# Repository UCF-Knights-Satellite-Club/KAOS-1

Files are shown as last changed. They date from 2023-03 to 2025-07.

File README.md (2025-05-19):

# KAOS-1 Project
KAOS (Knight Air Observer Satellite)-1 is a 4U CubeSat that will be launched on a weather balloon to study atmospheric chemistry.

## Hardware
TODO: add hardware description

## Software
This project utilizes the Arduino ecosystem on a **DOIT ESP32 DEVKIT V1**. Unless stated otherwise, all libraries can be found in the Arduino IDE Library Manager.

### Prerequisites
- **Arduino ESP32 Core** ([installation instructions](https://docs.espressif.com/projects/arduino-esp32/en/latest/installing.html))
- **Adafruit BMP3XX Library** by Adafruit
- **Adafruit SCD30** by Adafruit
- **RTClib** by Adafruit
- **Adafruit MMA8451 Library** by Adafruit
- **Arducam_Mega** by Arducam

### Explanation
The flight software has five states. The first state is `CALIBRATION` which averages several altitude readings to determine a launch altitude. Next is `PREFLIGHT` which runs when KAOS-1 is on the ground and waiting to be released on the balloon. High acceleration or breaking an altitude threshold will move to the `ASCENT` state. In this state, KAOS-1 monitors acceleration to determine when it is in free fall. In free fall, the accelerometer will read close to zero. Once this condition is met, the state moves to `FREEFALL` where altitude is compared to the deployment altitude. Once deployment altitude is reached, the a buzzer is enabled and the state switches to `LANDING`.

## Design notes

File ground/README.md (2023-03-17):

# Ground Software
This is all software that will not be put onto the flight board.

# Examples
Hardware test programs, misc. test programs, mech cad files

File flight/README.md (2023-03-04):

# Flight Software
This folder is for storing flight software (the programs that our flight board will run for all necessary functions)

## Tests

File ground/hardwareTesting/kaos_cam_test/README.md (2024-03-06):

# KAOS Cam Test
Takes images using an ArduCam Mega SPI camera and writes them to an SD card.

## Required Libraries
- **ESP-32** by Espressif ([Install Instructions](https://docs.espressif.com/projects/arduino-esp32/en/latest/installing.html))
- **Arducam_Mega** by Arducam

## Wiring
|Chip |ESP32 |
|---|---|
|ArduCam SCK (White) | 18 (D18) |
|ArduCam MISO (Brown)  | 19 (D18) |
|ArduCam MOSI (Yellow) | 23 (D23) |
|ArduCam CS (Orange) | 17 (TX2) |
|SD CLK | 18 (D18) |
|SD DI | 23 (D23) |
|SD DO | 19 (D18) |
|SD CS | 15 (D15) |

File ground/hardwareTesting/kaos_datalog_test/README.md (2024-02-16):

# KAOS Datalog Test
Gathers data from the sensors and logs them to the SD card in CSV format. Also outputs data over the serial connection which can be viewed with the Arduino IDE Serial Plotter Tool.

## Required Libraries
- **ESP-32** by Espressif ([Install Instructions](https://docs.espressif.com/projects/arduino-esp32/en/latest/installing.html))
- **Adafruit SCD-30** by Adafruit
- **RTClib** by Adafruit
- **Adafruit BMP3XX Library** by Adafruit

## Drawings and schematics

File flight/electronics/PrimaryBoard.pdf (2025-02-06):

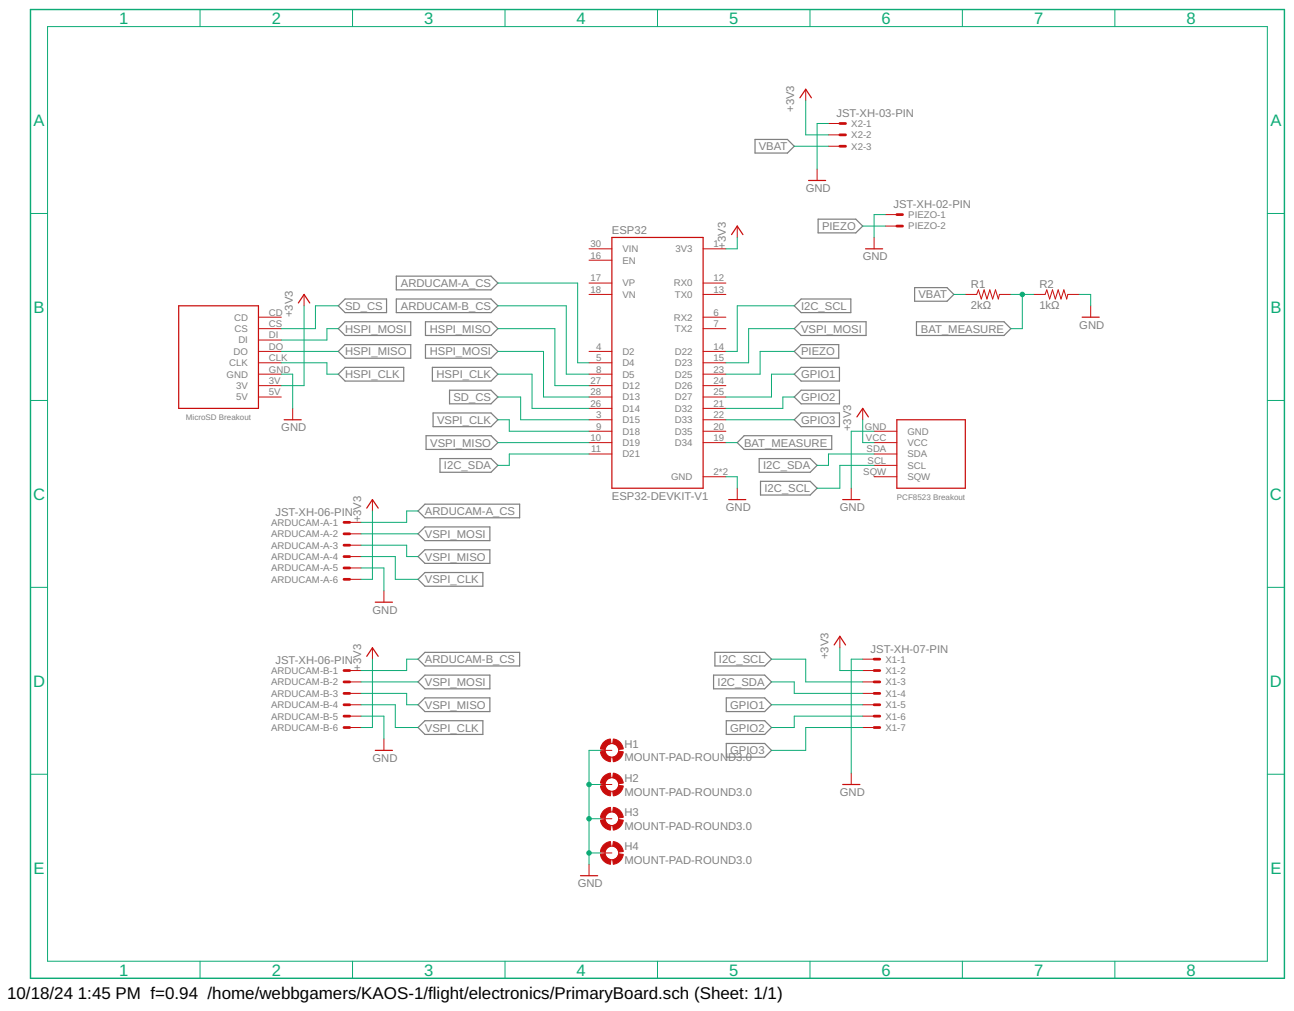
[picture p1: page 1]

GND JST-XH-06-PIN
ARDUCAM-A-1 ARDUCAM-A-2 ARDUCAM-A-3 ARDUCAM-A-4 ARDUCAM-A-5 ARDUCAM-A-6

JST-XH-06-PIN
ARDUCAM-B-1 ARDUCAM-B-2 ARDUCAM-B-3 ARDUCAM-B-4 ARDUCAM-B-5 ARDUCAM-B-6

10/18/24 1:45 PM f=0.94 /home/webbgamers/KAOS-1/flight/electronics/PrimaryBoard.sch (Sheet: 1/1)

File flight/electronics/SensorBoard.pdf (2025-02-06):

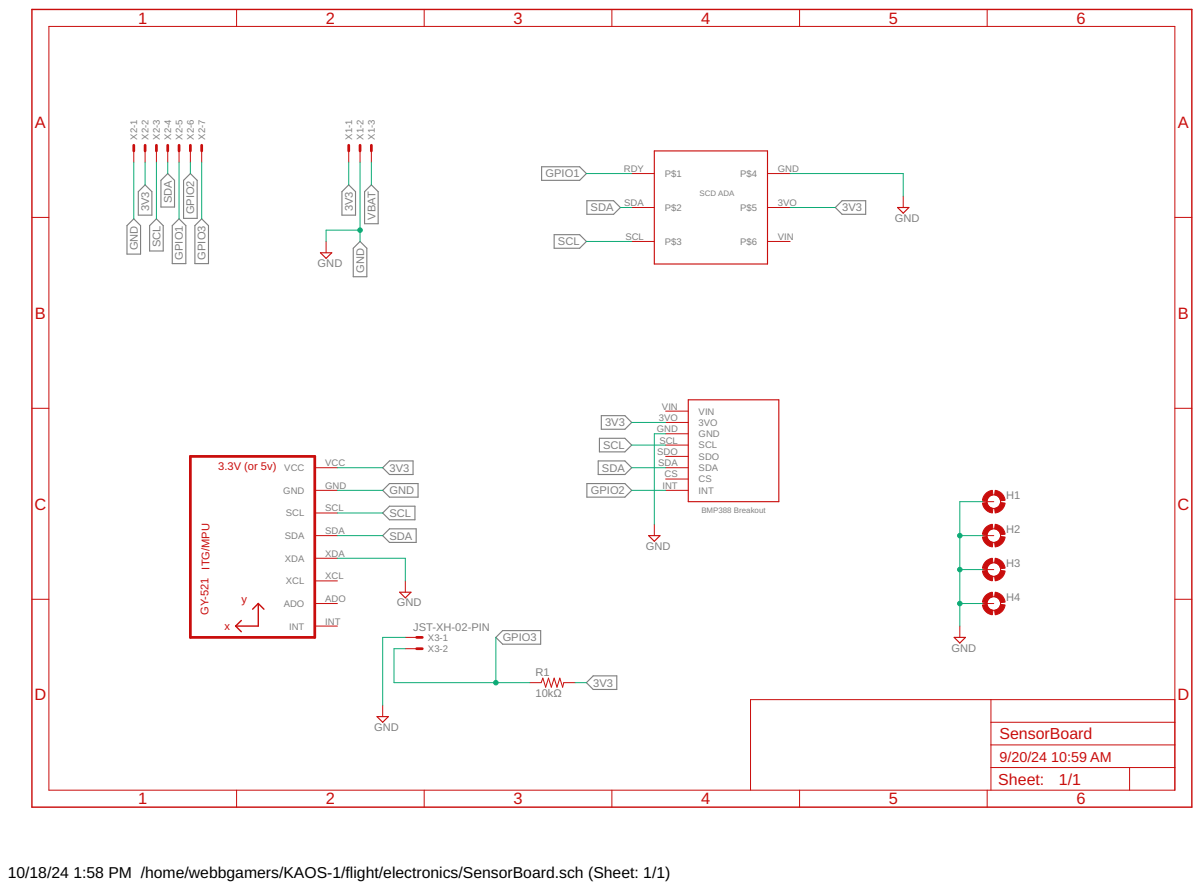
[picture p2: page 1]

10/18/24 1:58 PM /home/webbgamers/KAOS-1/flight/electronics/SensorBoard.sch (Sheet: 1/1)

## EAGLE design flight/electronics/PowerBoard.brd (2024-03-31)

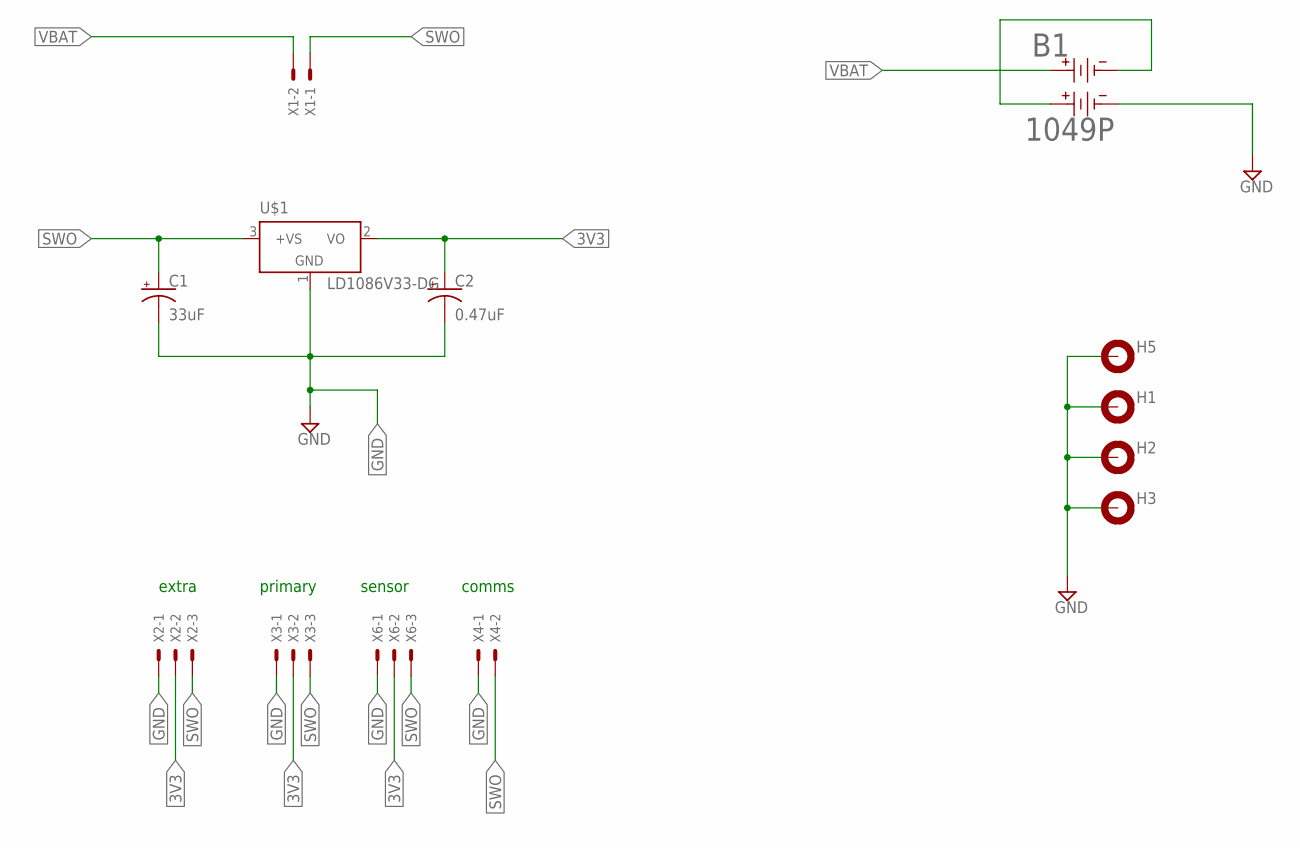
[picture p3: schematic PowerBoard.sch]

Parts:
B1: 1049P; 1049P_KEY
C1: 33uF; E2,5-5
C2: 0.47uF; E2,5-5
H1, H2, H3, H5: MOUNT-PAD-ROUND3.0; 3,0-PAD
U$1: LD1086V33-DG; TO220H
X1, X4: JST-XH-02-PIN; JST-XH_S2B
X2, X3, X6: JST-XH-03-PIN; JST-XH_S3B

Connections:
3V3: C2.+, U$1.2 (VO), X2.PIN2, X3.PIN2, X6.PIN2
GND: B1.3, C1.-, C2.-, H1.B3,0, H2.B3,0, H3.B3,0, H5.B3,0, U$1.1 (GND), X2.PIN1, X3.PIN1, X4.PIN1, X6.PIN1
unnamed: B1.2, B1.4
SWO: C1.+, U$1.3 (+VS), X1.PIN1, X2.PIN3, X3.PIN3, X4.PIN2, X6.PIN3
VBAT: B1.1, X1.PIN2

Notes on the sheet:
extra
primary
sensor
comms

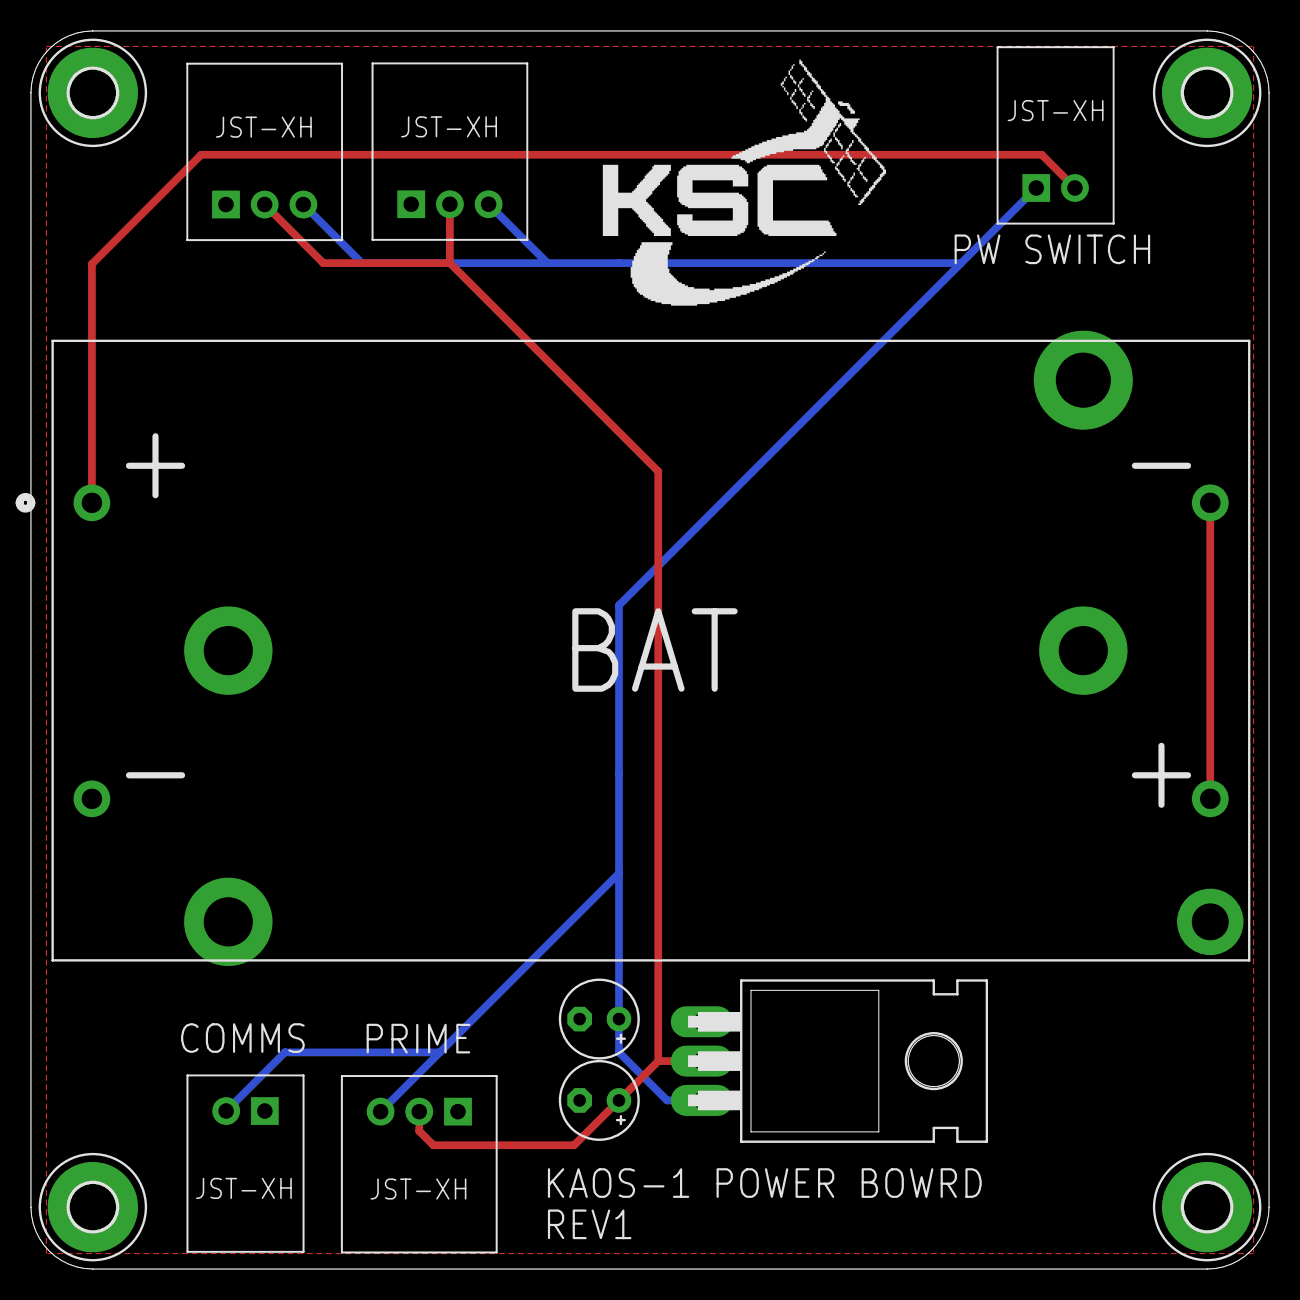
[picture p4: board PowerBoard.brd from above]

Board: 2 copper layers, 80.0 x 80.0 mm, 13 parts (0 on the bottom side), 5 nets.

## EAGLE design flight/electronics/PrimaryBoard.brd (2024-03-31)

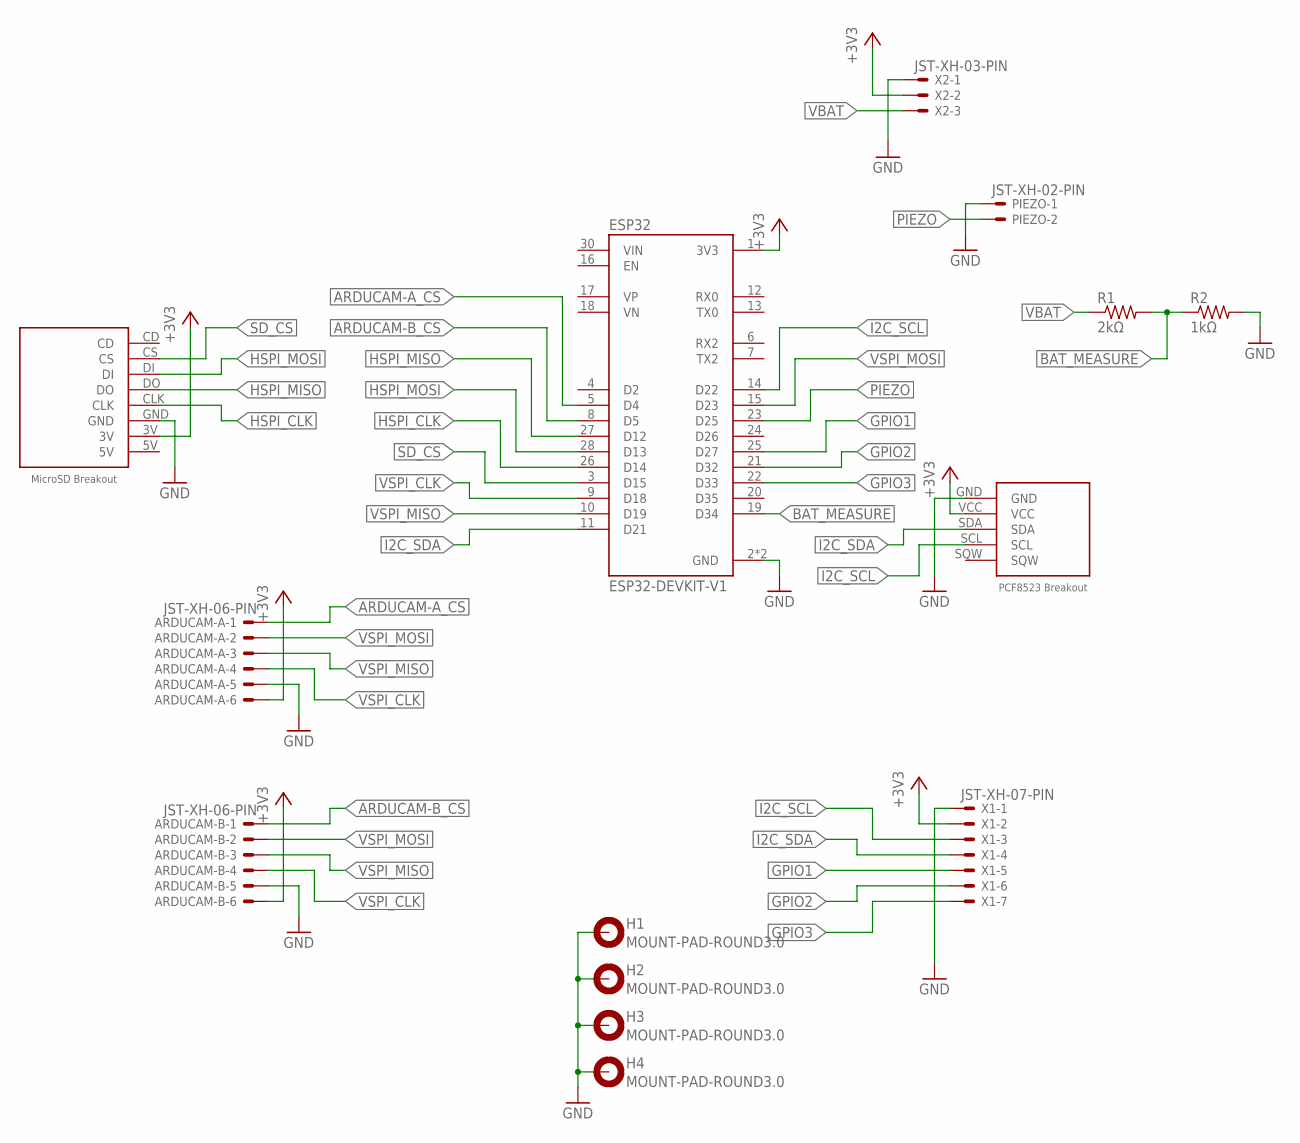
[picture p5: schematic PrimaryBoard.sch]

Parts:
ARDUCAM-A: JST-XH-06-PIN; JST-XH_S6B
ARDUCAM-B: JST-XH-06-PIN; JST-XH_S6B
ESP32: ESP32-DEVKIT-V1; MODULE_ESP32_DEVKIT_V1
H1, H2, H3, H4: MOUNT-PAD-ROUND3.0; 3,0-PAD
PIEZO: JST-XH-02-PIN; JST-XH_S2B
R1: 2kΩ; 0207/10
R2: 1kΩ; 0207/10
U$1: MICROSDBREAKOUT5V
U$2: PCF8523BREAKOUT
X1: JST-XH-07-PIN; JST-XH_S7B
X2: JST-XH-03-PIN; JST-XH_S3B

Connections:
+3V3: ARDUCAM-A.PIN6, ARDUCAM-B.PIN6, ESP32.1 (3V3), U$1.3V, U$2.VCC, X1.PIN2, X2.PIN2
ARDUCAM-A_CS: ARDUCAM-A.PIN1, ESP32.5 (D4)
ARDUCAM-B_CS: ARDUCAM-B.PIN1, ESP32.8 (D5)
BAT_MEASURE: ESP32.19 (D34), R1.2, R2.1
GND: ARDUCAM-A.PIN5, ARDUCAM-B.PIN5, ESP32.2 (GND), ESP32.29 (GND), H1.B3,0, H2.B3,0, H3.B3,0, H4.B3,0, PIEZO.PIN1, R2.2, U$1.GND, U$2.GND, X1.PIN1, X2.PIN1
GPIO1: ESP32.25 (D27), X1.PIN5
GPIO2: ESP32.21 (D32), X1.PIN6
GPIO3: ESP32.22 (D33), X1.PIN7
HSPI_CLK: ESP32.26 (D14), U$1.CLK
HSPI_MISO: ESP32.27 (D12), U$1.DO
HSPI_MOSI: ESP32.28 (D13), U$1.DI
I2C_SCL: ESP32.14 (D22), U$2.SCL, X1.PIN3
I2C_SDA: ESP32.11 (D21), U$2.SDA, X1.PIN4
PIEZO: ESP32.23 (D25), PIEZO.PIN2
SD_CS: ESP32.3 (D15), U$1.CS
VBAT: R1.1, X2.PIN3
VSPI_CLK: ARDUCAM-A.PIN4, ARDUCAM-B.PIN4, ESP32.9 (D18)
VSPI_MISO: ARDUCAM-A.PIN3, ARDUCAM-B.PIN3, ESP32.10 (D19)
VSPI_MOSI: ARDUCAM-A.PIN2, ARDUCAM-B.PIN2, ESP32.15 (D23)

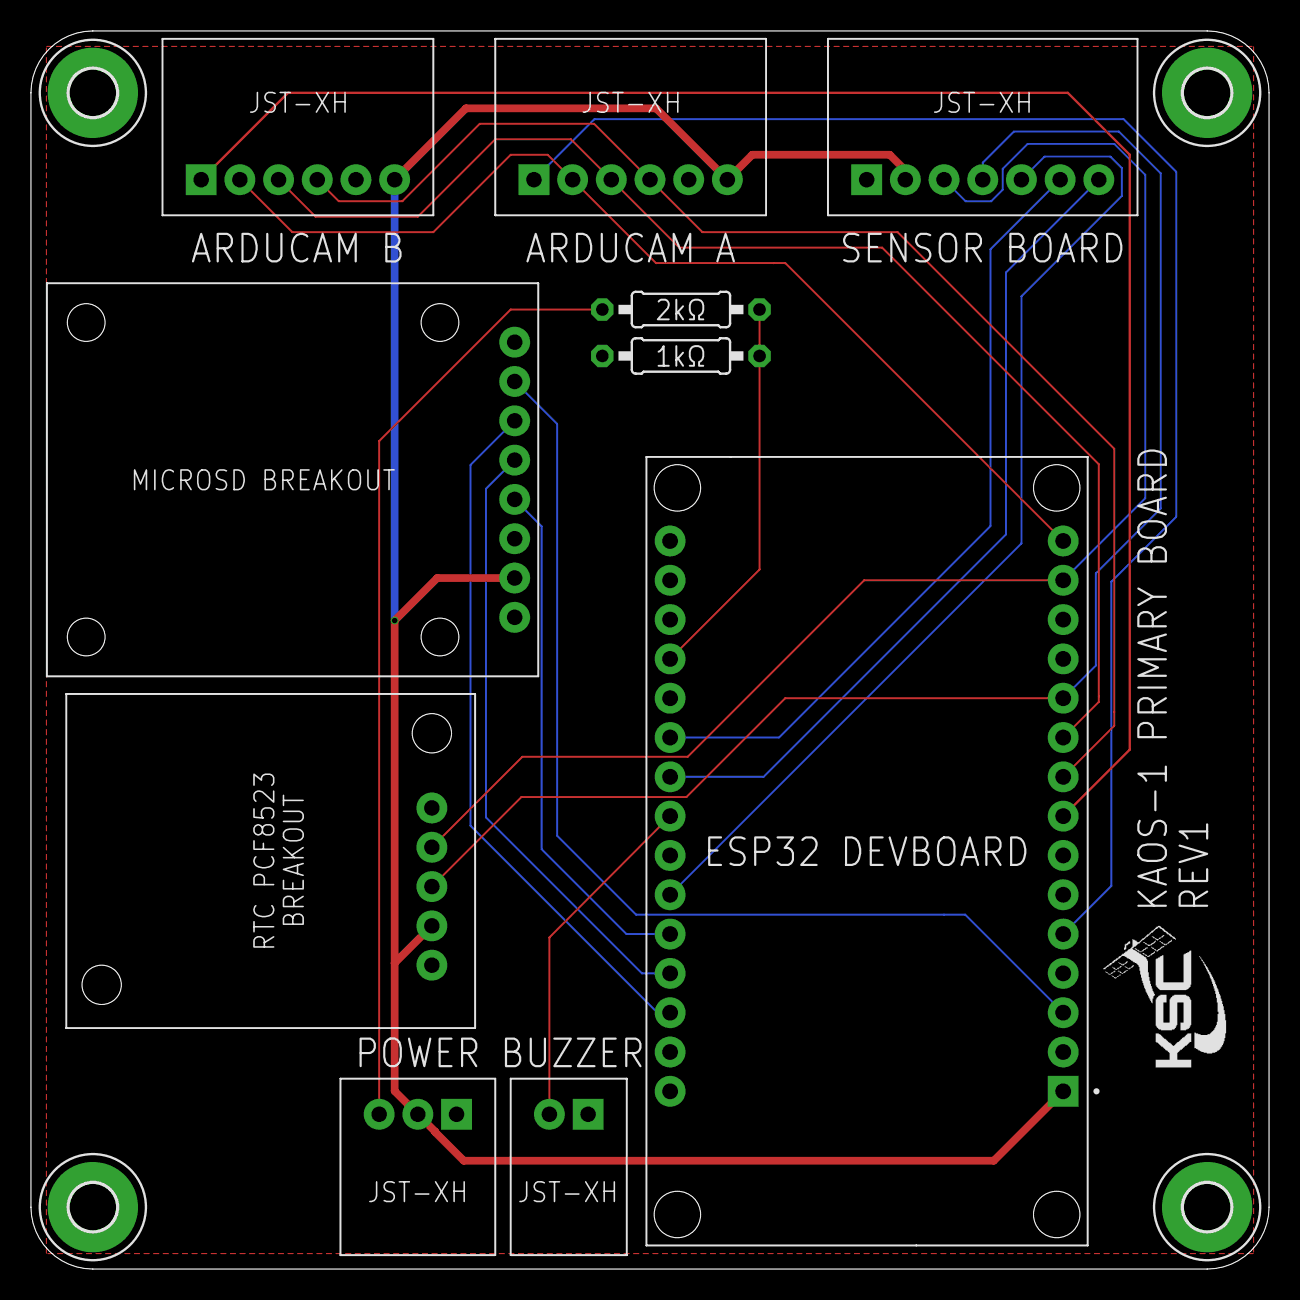
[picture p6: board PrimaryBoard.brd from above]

Board: 2 copper layers, 80.0 x 80.0 mm, 14 parts (0 on the bottom side), 19 nets.

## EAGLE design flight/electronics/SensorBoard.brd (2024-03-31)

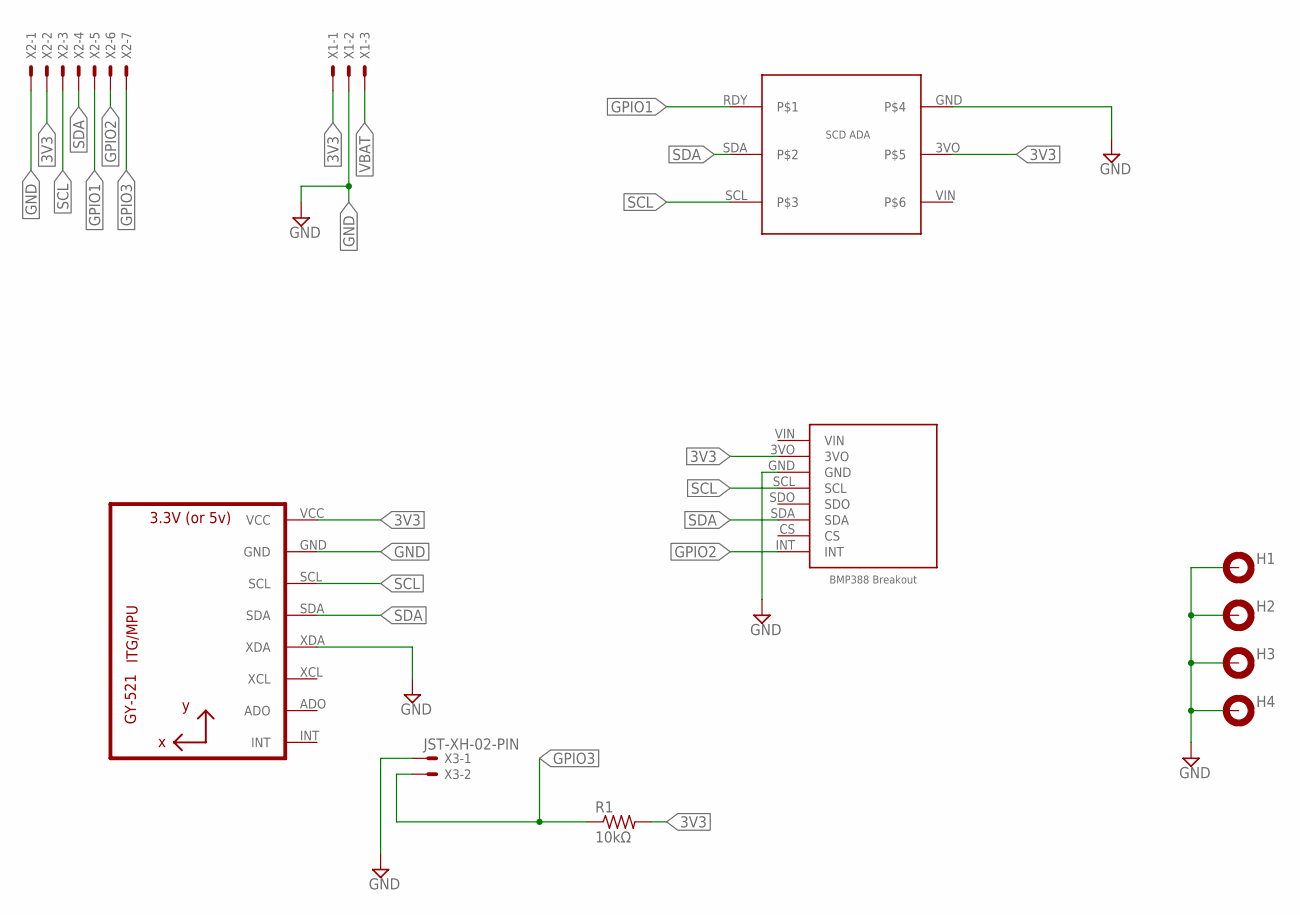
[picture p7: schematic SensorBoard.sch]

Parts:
H1, H2, H3, H4: MOUNT-PAD-ROUND3.0; 3,0-PAD
R1: 10kΩ; 0204/7
U1: GY-521MPU6050; GY-521
U$2: BMP388BREAKOUT
U$6: SCD30_ADA
X1: JST-XH-03-PIN; JST-XH_S3B
X2: JST-XH-07-PIN; JST-XH_S7B
X3: JST-XH-02-PIN; JST-XH_S2B

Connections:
3V3: R1.2, U1.VCC, U$2.3VO, U$6.3VO, X1.PIN1, X2.PIN2
GND: H1.B3,0, H2.B3,0, H3.B3,0, H4.B3,0, U1.GND, U1.XDA, U$2.GND, U$6.GND, X1.PIN2, X2.PIN1, X3.PIN1
GPIO1: U$6.RDY, X2.PIN5
GPIO2: U$2.INT, X2.PIN6
GPIO3: R1.1, X2.PIN7, X3.PIN2
SCL: U1.SCL, U$2.SCL, U$6.SCL, X2.PIN3
SDA: U1.SDA, U$2.SDA, U$6.SDA, X2.PIN4
VBAT: X1.PIN3

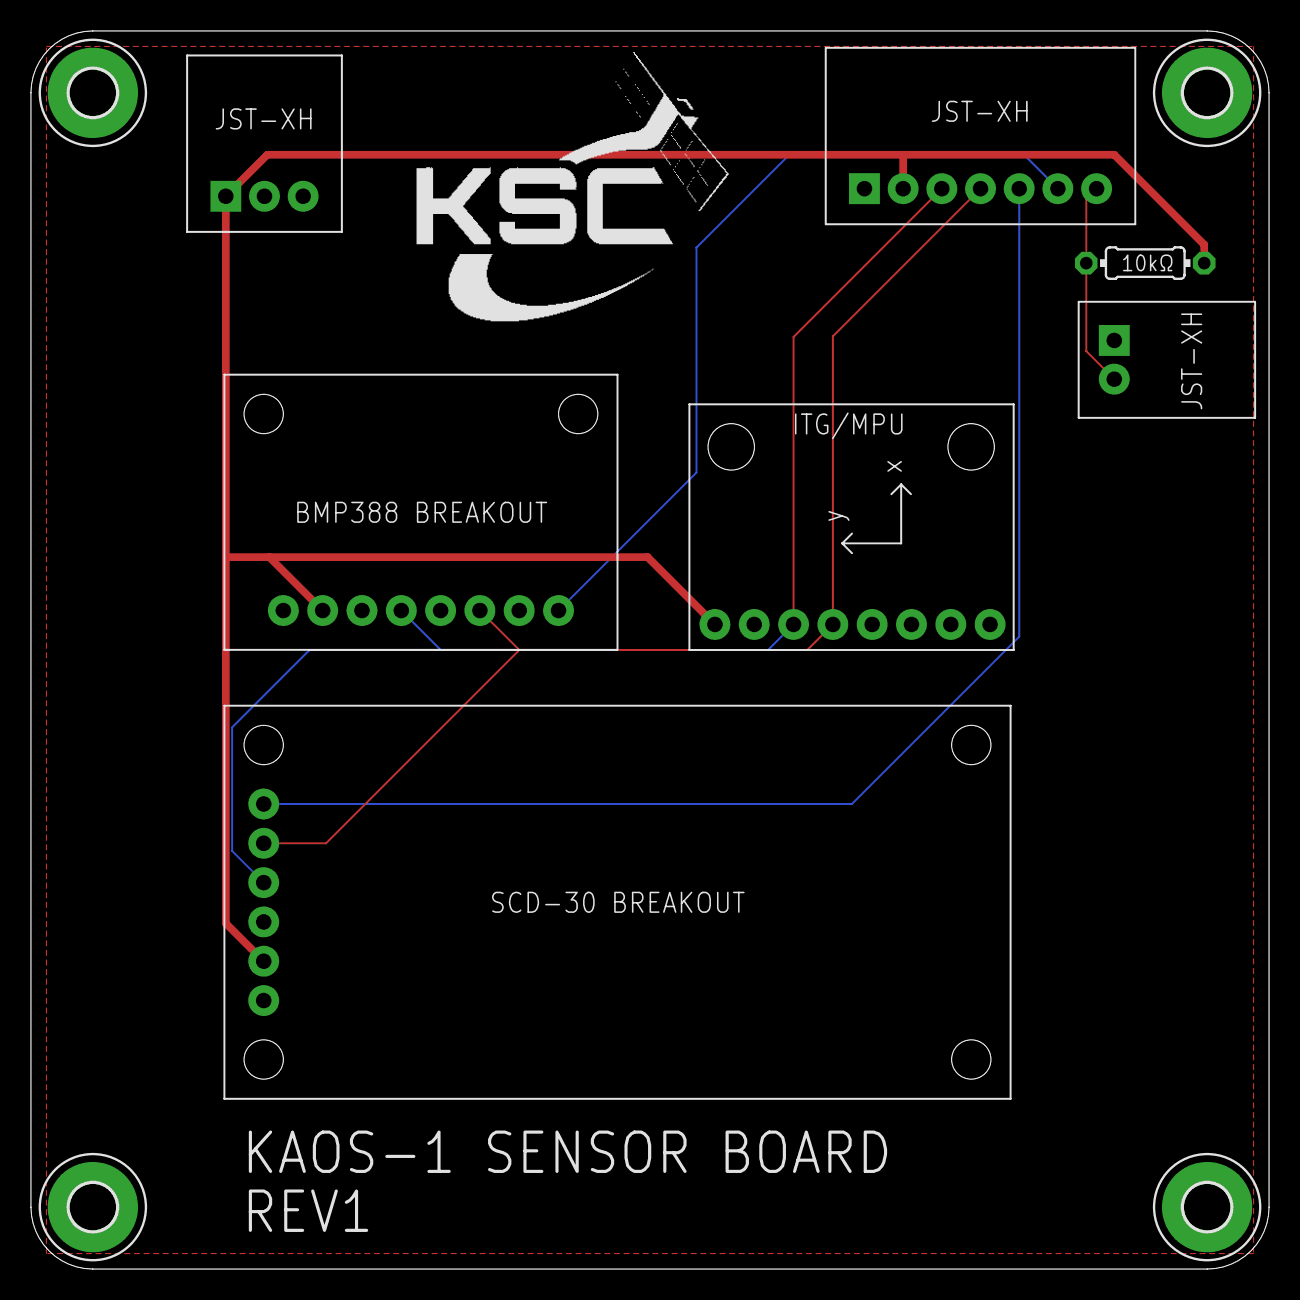
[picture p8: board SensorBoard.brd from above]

Board: 2 copper layers, 80.0 x 80.0 mm, 11 parts (0 on the bottom side), 7 nets.

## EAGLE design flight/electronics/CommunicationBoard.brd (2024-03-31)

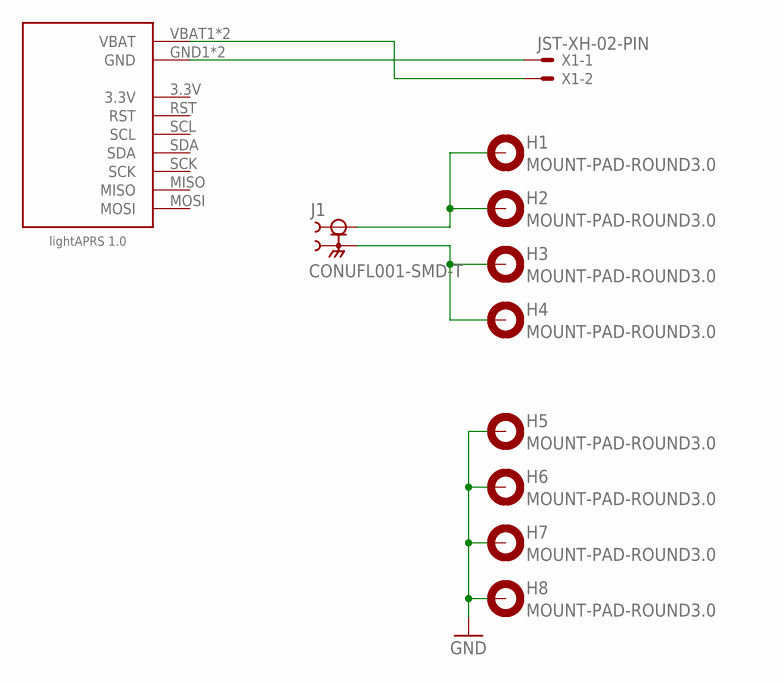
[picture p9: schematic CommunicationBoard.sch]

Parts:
H1, H2, H3, H4, H5, H6, H7, H8: MOUNT-PAD-ROUND3.0; 3,0-PAD
J1: CONUFL001-SMD-T; LINX_CONUFL001-SMD-T
U$1: LIGHTAPRS
X1: JST-XH-02-PIN; JST-XH_S2B

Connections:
GND: H5.B3,0, H6.B3,0, H7.B3,0, H8.B3,0, U$1.GND1 (GND), U$1.GND2 (GND), X1.PIN1
SIG+: H1.B3,0, H2.B3,0, J1.1
SIG-: H3.B3,0, H4.B3,0, J1.2, J1.3 (2)
VBAT: U$1.VBAT1 (VBAT), U$1.VBAT2 (VBAT), X1.PIN2

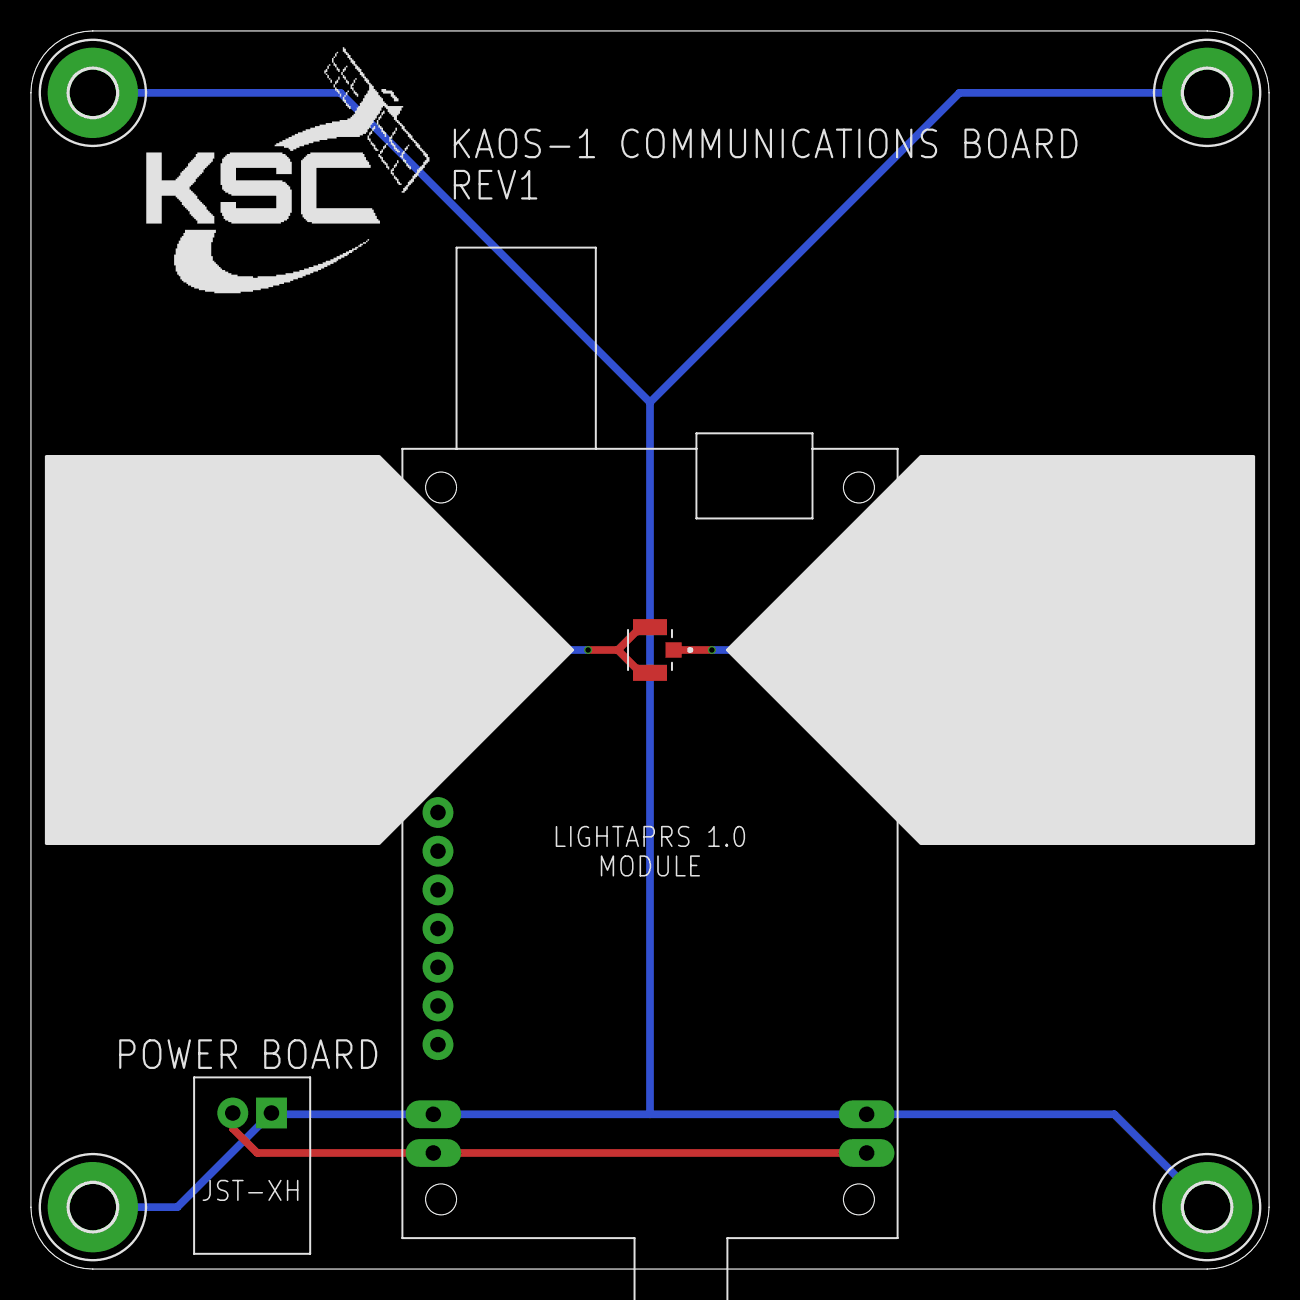
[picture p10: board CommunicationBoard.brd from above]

Board: 2 copper layers, 80.0 x 80.0 mm, 11 parts (0 on the bottom side), 4 nets.

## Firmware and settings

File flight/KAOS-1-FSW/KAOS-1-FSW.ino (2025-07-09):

//Including the libraries that we will be using in the code
#include <Wire.h>  //Allows communication between Arduino and the other devices

//Libraries for sensor use and data collection
#include <Adafruit_Sensor.h>  //Gives a unified interface for a bunch of adafruit sensors
#include <Adafruit_BMP3XX.h>  //Library for the barometer

//Libraries for the camera and interface with the camera
#include <Arducam_Mega.h>  //Library for interface with the Camera
#include <Arducam/Platform.h>

//Libraries for data storage and transfer
#include <SPI.h>  //Library for data transfer
#include <FS.h>   //Library that provides file operations for storage on the SD card
#include <SD.h>   //Library used for interfacing with SD cards

#include <Adafruit_SCD30.h>
#include "RTClib.h"
#include "driver/i2c.h"

// Pin constants
#define CAM_CS_A 4
#define CAM_CS_B 5
#define HSPI_MISO 12
#define HSPI_MOSI 13
#define HSPI_CLK 14
#define SD_CS 15
#define VSPI_CLK 18
#define VSPI_MISO 19
#define I2C_SDA 21
#define I2C_SCL 22
#define VSPI_MOSI 23
#define BUZZER_PIN 25
#define SCD30_RDY 27
#define BMP388_INT 32
#define THERMISTOR 33
#define BATT_VOLTAGE 34


// Depending on the selected board, may or may not be defined already
#ifndef LED_BUILTIN
#define LED_BUILTIN 2
#endif

// Constants
#define SEALEVELPRESSURE_HPA (1013.25)        // standard pressure at sea level
#define PIC_BUFFER_SIZE 254                   // buffer size to store images, must be less than 255
#define CAM_IMAGE_MODE CAM_IMAGE_MODE_WQXGA2  // ArduCam image mode
#define SPI_CLOCK_DIV SPI_CLOCK_DIV16         // SPI clock divider, lowers SPI clock speeds to prevent image corruption
#define LOG_QUEUE_SIZE 50                     // how many entries to store before dropping data
#define SPI_MUTEX_WAIT 20                     // how many ms to wait for SPI mutex lock before giving up
#define LOG_DELAY 100                         // how many ms to wait between logging to SD
#define CALIBRATION_COUNT 20                  // how many measurements to average when determining initial altitude
#define ASCENT_ACCEL_THRESHOLD 20             // acceleration above which PREFLIGHT moves to ASCENT
#define MAX_PREFLIGHT_ALTITUDE 5              // altitude where PREFLIGHT automatically switches to ASCENT
#define ALTITUDE_CHECK_DELAY 50               // ms between altitude checks
#define FREEFALL_ACCEL_THRESHOLD 2            // acceleration below which to switch from ASCENT to FREEFALL
#define FREEFALL_VELOCITY_THRESHOLD 3         // decent speed above which to swtich from ASCENT to FREEFALL
#define PARACHUTE_DEPLOY_ALTITUDE 80          // altutude to switch from FREEFALL to LANDING
#define ALTITUDE_DELTA_FILTER_GAIN 0.95       // between 0 and 1, higher number means each measurement has lower impact on estimate
#define ACCEL_FILTER_GAIN 0.5                 // same as altitude
#define THERMISTORNOMINAL 7300               // resistance at 25 degrees C of thermistor
#define TEMPERATURENOMINAL 25                 // temp. for nominal resistance of thermistor (almost always 25 C)
#define BCOEFFICIENT 3950                     // The beta coefficient of the thermistor (usually 3000-4000)
#define THERM_TEMP_FILTER_GAIN 0.95
#define SERIESRESISTOR 10000                  // the value of the 'other' resistor connected to the thermistor
#define BUZZER_INTERVAL 500

// Peripheral globals
Adafruit_BMP3XX bmp;
Arducam_Mega camA(CAM_CS_A);
//Arducam_Mega camB(CAM_CS_B);


// Function definitions
void write_pic(Arducam_Mega &cam, File dest);
void calibrationRun();
void preflightRun();
void ascentRun();
void freefallRun();
void landingRun();
void checkAltitude(void *parameter);
void cameraCapture(void *parameter);
void logData(void *parameter);
void Tempreading(float* temp, float* resistance);

// Globals
static TaskHandle_t check_altitude;
static TaskHandle_t log_data;
static TaskHandle_t camera_capture;
static SemaphoreHandle_t spi_mutex;
static QueueHandle_t log_queue;
bool sd_fail = false;
int pic_num = 0;
char base_dir[20];
float start_altitude = 0;
int calibration_count = 0;
float altitude_delta_estimate = 0;
float prev_altitude_delta_estimate = 0;
float accel_x_estimate = 0;
float prev_accel_x_estimate = 0;
float accel_y_estimate = 0;
float prev_accel_y_estimate = 0;
float accel_z_estimate = 0;
float prev_accel_z_estimate = 0;
float accel_magnitude = 0;
float absolute_altitude = 0;
float ground_altitude = 0;
float altitude_delta = 0;
float prev_altitude = 0;
float therm_temp_estimate = 0;
float prev_therm_temp_estimate = 0;
char logpath[35];
int logindex = 0;

// Describes current flight state
typedef enum {
  CALIBRATION,  // establishing altitude baseline
  PREFLIGHT,    // waiting for launch
  ASCENT,       // rising on balloon
  FREEFALL,     // detached from balloon
  LANDING,      // parachute deployed
} FlightState;

// All the data that gets logged
typedef struct {
  int index;
  double temperature;
  double pressure;
  float altitude;
  float accel_x;
  float accel_y;
  float accel_z;
  float accel_filtered;
  float ascent_velocity_filtered;
  float therm_resistance;
  float therm_temp;
  FlightState flight_state;
} DataPoint;

FlightState flight_state = LANDING;
Adafruit_SCD30 scd30;
RTC_DS1307 rtc;

//SPIClass *vspi;
SPIClass *hspi;

bool data_ready = false;

void IRAM_ATTR scd30_ready() {
  data_ready = true;
}

void setup() {
  // LED on for entire setup process
  pinMode(LED_BUILTIN, OUTPUT);
  digitalWrite(LED_BUILTIN, HIGH);

  // BUZZER PINMODE
  pinMode(BUZZER_PIN, OUTPUT);

  // init serial
  Serial.begin(115200);

  hspi = new SPIClass(HSPI);

  Wire.begin();
  //i2c_set_timeout((i2c_port_t)I2C_NUM_0, 0xFFFFF);



  // BMP388 SETUP
  Serial.println("Setting up BMP sensor");
  if (!bmp.begin_I2C()) {
    Serial.println("Could not find a valid BMP3 sensor.");
    return;
  }
  bmp.setTemperatureOversampling(BMP3_OVERSAMPLING_8X);
  bmp.setPressureOversampling(BMP3_OVERSAMPLING_4X);
  bmp.setIIRFilterCoeff(BMP3_IIR_FILTER_COEFF_3);
  bmp.setOutputDataRate(BMP3_ODR_50_HZ);

  // SCD30 SETUP
  Serial.println("Setting up SCD30");
  if (!scd30.begin()) {
    Serial.println("Failed to find SCD30 chip");
    return;
  }

  // RTC SETUP
  Serial.println("Setting up RTC");
  if (!rtc.begin()) {
    Serial.println("Couldn't find RTC");
    return;
  }

  // Camera setup
  Serial.println("Initializing ArduCam A");
  camA.begin();
  //Serial.println("Initializing ArduCam B");
  //camB.begin();

  // SD CARD SETUP
  Serial.println("Setting up SD card");
  if (!SD.begin(SD_CS, *hspi)) {
    Serial.println("Card Mount Failed");
    return;
  }
  uint8_t cardType = SD.cardType();

  if (cardType == CARD_NONE) {
    Serial.println("No SD card attached");
    return;
  }
  
  // Configure SCD30 RDY interrupt
  pinMode(SCD30_RDY, INPUT_PULLDOWN);
  attachInterrupt(SCD30_RDY, scd30_ready, RISING);

  // Queues data to be logged to SD
  log_queue = xQueueCreate(LOG_QUEUE_SIZE, sizeof(DataPoint));
  if (log_queue == NULL) {
    Serial.print("Unable to create log queue");
    while (1) {}
  }

  // Used to prevent simultaneous SPI access from causing problems
  spi_mutex = xSemaphoreCreateMutex();
  if (spi_mutex == NULL) {
    Serial.print("Unable to create SPI mutex");
    while (1) {}
  }

  // Must be called after setting up SD and ArduCam since they will reset this
  SPI.setClockDivider(SPI_CLOCK_DIV);

  if (!sd_fail) {
    // Pick base directory for this flight
    int i = 0;
    do {
      sprintf(base_dir, "/KAOS-log%d", i);
      i++;
    } while (SD.exists(base_dir));
    SD.mkdir(base_dir);
    Serial.print("Data from this run stored in ");
    Serial.println(base_dir);
    sprintf(logpath, "%s/data.csv", base_dir);

    // Write CSV header
    File log_file = SD.open(logpath, FILE_APPEND);
    if (log_file) {
      log_file.println("index,bmp_temp,pressure,altitude,accelx,accely,accelz,accel_filtered,ascent_velocity,therm_resistance, therm_temp,state");
      log_file.close();
    }
  }

  // Create task for sensor checks
  xTaskCreatePinnedToCore(
    checkAltitude,     // Function to call
    "Check Altitude",  // Task name
    4096,              // Memory allocated
    NULL,              // Parameters to pass to the function
    2,                 // Priority (higher number = higher priority)
    &check_altitude,   // Task handle
    0                  // Core
  );

  // Create task for taking pictures
  xTaskCreatePinnedToCore(
    cameraCapture,
    "Camera Capture",
    4096,
    NULL,
    tskIDLE_PRIORITY,  // Lowest possible priority, see https://www.freertos.org/Documentation/02-Kernel/02-Kernel-features/01-Tasks-and-co-routines/15-Idle-task
    &camera_capture,
    0);

  // Create task for logging data to SD
  xTaskCreatePinnedToCore(
    logData,
    "Log Data",
    4096,
    NULL,
    1,
    &log_data,
    0);

  // Delay to stop first image from being green
  vTaskDelay(500 / portTICK_PERIOD_MS);

  // Unsuspend tasks
  vTaskResume(check_altitude);
  if (!sd_fail) {
    vTaskResume(camera_capture);
    vTaskResume(log_data);
  }

  // LED off once setup complete
  digitalWrite(LED_BUILTIN, LOW);
}

// Empty loop function, all functionality in custom tasks
void loop() {
  vTaskDelay(1000 / portTICK_PERIOD_MS);
}

// Periodically monitors sensor data and performs state switches
void checkAltitude(void *parameter) {
  vTaskSuspend(NULL);  // Initially suspend task

  TickType_t last_wake = xTaskGetTickCount();



  while (1) {
    /*
    Serial.print("absolute alt: ");
    Serial.println(absolute_altitude);
    Serial.print("start alt: ");
    Serial.println(start_altitude);
    Serial.print("alt: ");
    Serial.println(ground_altitude);
    */

    // Get altitude data
    bmp.performReading();
    absolute_altitude = calculateAltitude(bmp.pressure);
    ground_altitude = absolute_altitude - start_altitude;
    altitude_delta = absolute_altitude - prev_altitude;
    prev_altitude = absolute_altitude;

    // Get imu data
    //mma.read();
    float accel_x = 0;
    float accel_y = 0;
    float accel_z = 0;

    // Lowpass filter, smoothes out noisy data
    altitude_delta_estimate = (ALTITUDE_DELTA_FILTER_GAIN * prev_altitude_delta_estimate) + (1 - ALTITUDE_DELTA_FILTER_GAIN) * altitude_delta;
    prev_altitude_delta_estimate = altitude_delta_estimate;

    accel_x_estimate = (ACCEL_FILTER_GAIN * prev_accel_x_estimate) + (1 - ACCEL_FILTER_GAIN) * accel_x;
    prev_accel_x_estimate = accel_x_estimate;

    accel_y_estimate = (ACCEL_FILTER_GAIN * prev_accel_y_estimate) + (1 - ACCEL_FILTER_GAIN) * accel_y;
    prev_accel_y_estimate = accel_y_estimate;

    accel_z_estimate = (ACCEL_FILTER_GAIN * prev_accel_z_estimate) + (1 - ACCEL_FILTER_GAIN) * accel_z;
    prev_accel_z_estimate = accel_z_estimate;


    accel_magnitude = sqrtf(accel_x_estimate * accel_x_estimate + accel_y_estimate * accel_y_estimate + accel_z_estimate * accel_z_estimate);

    float temp, resistance;
    Tempreading(&temp, &resistance);
    

    therm_temp_estimate = (THERM_TEMP_FILTER_GAIN * prev_therm_temp_estimate) + (1- THERM_TEMP_FILTER_GAIN) * temp;
    prev_therm_temp_estimate = therm_temp_estimate;

    /*
    Serial.print("accel:");
    Serial.println(accel_estimate);
    */

    // Core state machine
    switch (flight_state) {
      case CALIBRATION:
        /* CALIBRATE: averages measurements to
       * determine a launch altitude. */
        calibrationRun();
        break;
      case PREFLIGHT:
        /* PRE-LAUNCH: waiting on the ground to be released. Detects
       * launch by breaking an altitude rate of change threshold
       * or passing a certain altitude.       - > ASCENT         */
        preflightRun();
        break;
      case ASCENT:
        /* ASCENT: Rising up to the extent of the tether and waiting
       * for the burn wire to trigger and free fall to begin.
       * Detects this by breaking an altitude rate of change
       * threshold (or accelerometer info)    - > FREEFALL       */
        ascentRun();
        break;
      case FREEFALL:
        /* FREE FALL: falling through the air and waiting to
       * hit the parachute deployment altitude.  - > LANDING      */
        freefallRun();
        break;
      case LANDING:
        /* LANDING: Deploy parachute. Final State. */
        landingRun();
        break;
    }

    if (!sd_fail) {
      if (uxQueueSpacesAvailable(log_queue) >= 1) {
        DataPoint data_point = {
          logindex,
          bmp.temperature,
          bmp.pressure,
          ground_altitude,
          accel_x,
          accel_y,
          accel_z,
          accel_magnitude,
          altitude_delta_estimate * 1000 / ALTITUDE_CHECK_DELAY,
          resistance,
          therm_temp_estimate,
          flight_state
        };
        if (xQueueSendToBack(log_queue, &data_point, 0) == pdFALSE) {
          Serial.println("Failed to add data to queue");
        }
      } else {
        Serial.println("WARNING: Log queue is full, some data is getting dropped");
      }

      logindex++;
    }
  }
}


void cameraCapture(void *parameter) {
  vTaskSuspend(NULL);  // Initially suspend task
  while (1) {
    Serial.println("Taking picture");
    camA.takePicture(CAM_IMAGE_MODE, CAM_IMAGE_PIX_FMT_JPG);
    char fp[35];
    sprintf(fp, "%s/pic%d.jpg", base_dir, pic_num);
    pic_num++;
    Serial.println("Saving picture");
    if (xSemaphoreTake(spi_mutex, SPI_MUTEX_WAIT) == pdTRUE) {
      File file = SD.open(fp, FILE_WRITE);
      xSemaphoreGive(spi_mutex);
      write_pic(camA, file);
      Serial.print("Picutre saved to ");
      Serial.println(fp);
    }
  }
}

void logData(void *parameter) {
  vTaskSuspend(NULL);  // Initially suspend task
  while (1) {
    if (uxQueueMessagesWaiting(log_queue) > 0) {
      if (xSemaphoreTake(spi_mutex, SPI_MUTEX_WAIT) == pdTRUE) {
        File log_file = SD.open(logpath, FILE_APPEND);
        if (log_file) {
          DataPoint data_point;
          while (xQueueReceive(log_queue, &data_point, 0) == pdTRUE) {
            log_file.print(data_point.index);
            log_file.print(",");
            log_file.print(data_point.temperature);
            log_file.print(",");
            log_file.print(data_point.pressure);
            log_file.print(",");
            log_file.print(data_point.altitude);
            log_file.print(",");
            log_file.print(data_point.accel_x);
            log_file.print(",");
            log_file.print(data_point.accel_y);
            log_file.print(",");
            log_file.print(data_point.accel_z);
            log_file.print(",");
            log_file.print(data_point.accel_filtered);
            log_file.print(",");
            log_file.print(data_point.ascent_velocity_filtered);
            log_file.print(",");
            log_file.print(data_point.therm_resistance);
            log_file.print(",");
            log_file.print(data_point.therm_temp);
            log_file.print(",");
            log_file.println(data_point.flight_state);
          }
          log_file.close();
        } else {
          Serial.println("Error opening file");
        }
        xSemaphoreGive(spi_mutex);
      }
    }
    vTaskDelay(LOG_DELAY / portTICK_PERIOD_MS);
  }
}

/* ==== UTILITY FUNCTIONS ==== */

void write_pic(Arducam_Mega &cam, File dest) {

  uint8_t prev_byte = 0;
  uint8_t cur_byte = 0;
  uint8_t head_flag = 0;
  unsigned int i = 0;
  uint8_t image_buf[PIC_BUFFER_SIZE] = { 0 };
  uint32_t read_len = 0;
  uint8_t start_offset = 0;

  while (cam.getReceivedLength()) {
    start_offset = 0;
    if (xSemaphoreTake(spi_mutex, SPI_MUTEX_WAIT) == pdTRUE) {
      read_len = cam.readBuff(image_buf, PIC_BUFFER_SIZE);
      xSemaphoreGive(spi_mutex);
    } else {
      Serial.println("WARNING: SPI lock timeout exceeded");
      return;
    }
    // Search through buffer for start and end flags
    for (i = 0; i < read_len; i++) {
      // Store current and previous byte
      prev_byte = cur_byte;
      cur_byte = image_buf[i];

      // Start writing at JPEG file start (0xFFD8)
      if (prev_byte == 0xff && cur_byte == 0xd8) {
        Serial.print("Found jpeg start at i=");
        Serial.println(i);
        head_flag = 1;
        start_offset = i + 1;
        if (xSemaphoreTake(spi_mutex, SPI_MUTEX_WAIT) == pdTRUE) {
          dest.write(0xff);
          dest.write(0xd8);
          xSemaphoreGive(spi_mutex);
        } else {
          Serial.println("WARNING: SPI lock timeout exceeded");
          return;
        }
      }

      // Close file on JPEG file ending (0xFFD9)
      if (head_flag && prev_byte == 0xff && cur_byte == 0xd9) {
        Serial.print("Found jpeg end at i=");
        Serial.println(i);
        Serial.print("Writing buffer from ");
        Serial.print(start_offset);
        Serial.print(" with len ");
        Serial.println(i + 1 - start_offset);
        if (xSemaphoreTake(spi_mutex, SPI_MUTEX_WAIT) == pdTRUE) {
          dest.write(image_buf + start_offset, i + 1 - start_offset);
          dest.close();
          xSemaphoreGive(spi_mutex);
        } else {
          Serial.println("WARNING: SPI lock timeout exceeded");
        }
        return;
      }
    }

    // No end flag found, write the full buffer
    if (head_flag) {
      /*Serial.print("Writing buffer from ");
      Serial.print(start_offset);
      Serial.print(" with len ");
      Serial.println(PIC_BUFFER_SIZE - start_offset);*/
      if (xSemaphoreTake(spi_mutex, SPI_MUTEX_WAIT) == pdTRUE) {
        dest.write(image_buf + start_offset, read_len - start_offset);
        xSemaphoreGive(spi_mutex);
      } else {
        Serial.println("WARNING: SPI lock timeout exceeded");
        return;
      }
    }
  }

  // Did not find EOF, corrupted?
  Serial.println("WARNING: Did not find JPEG file ending in image data, possible corruption");
  if (xSemaphoreTake(spi_mutex, SPI_MUTEX_WAIT) == pdTRUE) {
    dest.close();
    xSemaphoreGive(spi_mutex);
  } else {
    Serial.println("WARNING: SPI lock timeout exceeded");
  }
}

float calculateAltitude(float atmospheric) {
  atmospheric = atmospheric / 100.0;
  return 44330.0 * (1.0 - pow(atmospheric / SEALEVELPRESSURE_HPA, 0.1903));
}

/* ================================= */

/* ==== STATE MACHINE FUNCTIONS ==== */

void calibrationRun() {
  // average several readings for baseline then move to PRELAUNCH
  start_altitude += absolute_altitude;
  calibration_count++;

  Serial.print("Calibrating altitude ");
  Serial.print(calibration_count);
  Serial.print("/");
  Serial.println(CALIBRATION_COUNT);

  if (calibration_count >= CALIBRATION_COUNT) {
    start_altitude /= CALIBRATION_COUNT;
    flight_state = PREFLIGHT;

    Serial.print("Starting altitude: ");
    Serial.println(start_altitude);
    Serial.println("Calibration complete, moving to PREFLIGHT");
  }
}

void preflightRun() {
  // move to ASCENT if acceleration is or altitude above threshold

  if (ground_altitude >= MAX_PREFLIGHT_ALTITUDE) {
    flight_state = ASCENT;
    Serial.println("Max preflight altitude exceeded, moving to ASCENT");

  } else if (accel_magnitude >= ASCENT_ACCEL_THRESHOLD) {
    flight_state = ASCENT;
    Serial.println("Acceleration threshold met, moving to ASCENT");
  }
}

void ascentRun() {
  // move to FREEFALL if acceleration is close to 0
  if (accel_magnitude <= FREEFALL_ACCEL_THRESHOLD) {
    flight_state = FREEFALL;
    digitalWrite(LED_BUILTIN, HIGH);
    Serial.println("Acceleration threshold met, moving to FREEFALL");
  }
  // move to FREEFALL if altitude is changing faast enough
  if (altitude_delta_estimate * 1000 / ALTITUDE_CHECK_DELAY < -FREEFALL_VELOCITY_THRESHOLD) {
    flight_state = FREEFALL;
    digitalWrite(LED_BUILTIN, HIGH);
    Serial.println("Decent velocity threshold met, moving to FREEFALL");
  }
}

void freefallRun() {
  // move to LANDING if below deployment altitude
  if (ground_altitude < PARACHUTE_DEPLOY_ALTITUDE) {
    flight_state = LANDING;

    Serial.println("Parachute deployment altitude reached, moving to LANDING");
  }
}

void landingRun() {
  // Deploy parachute, buzzer loop, last stage of flight
  static unsigned long previousmillis = 0;
  unsigned long currentmillis = millis();  // checks and updates time value for the upcoming calculations

  if (currentmillis - previousmillis >= BUZZER_INTERVAL) {
    previousmillis = currentmillis;  // updates previousmillis for the next run

    static bool buzzer_on = false;

    // below if statement will turn the buzzer on if buzzer_on is false.

    if (buzzer_on) {
      noTone(BUZZER_PIN);
    } else {
      tone(BUZZER_PIN, 3000);
    }

    buzzer_on = !buzzer_on;  // changes state for next run
  }
}


void Tempreading(float* temp, float* resistance) {
  float reading;

  reading = analogRead(THERMISTOR);

  // Serial.print("analog reading ");
  // Serial.println(reading);

  // convert the value to resistance
  reading = 4095 / reading - 1;
  reading = SERIESRESISTOR / reading;
  *resistance = reading;

  float steinhart;
  steinhart = reading / THERMISTORNOMINAL;           // (R/Ro)
  steinhart = log(steinhart);                        // ln(R/Ro)
  steinhart /= BCOEFFICIENT;                         // 1/B * ln(R/Ro)
  steinhart += 1.0 / (TEMPERATURENOMINAL + 273.15);  // + (1/To)
  steinhart = 1.0 / steinhart;                       // Invert
  steinhart -= 273.15;                               // convert absolute temp to C
  *temp = steinhart;                             
  // Serial.print("Temperature ");
  // Serial.print(steinhart);
  // Serial.println(" *C");
}

/* ================================= */

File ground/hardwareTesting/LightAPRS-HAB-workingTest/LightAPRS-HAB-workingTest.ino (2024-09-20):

#include <LibAPRS.h>        //Modified version of https://github.com/markqvist/LibAPRS
#include <SoftwareSerial.h>
#include <TinyGPS++.h>      //https://github.com/mikalhart/TinyGPSPlus
#include <LowPower.h>       //https://github.com/rocketscream/Low-Power
#include <Wire.h>
#include <Adafruit_BMP085.h>//https://github.com/adafruit/Adafruit-BMP085-Library
#include <avr/wdt.h>

#define RfPDPin     19
#define GpsVccPin   18
#define RfPwrHLPin  21
#define RfPttPin    20
#define BattPin     A2
#define PIN_DRA_RX  22
#define PIN_DRA_TX  23

#define ADC_REFERENCE REF_3V3
#define OPEN_SQUELCH false

#define GpsON         digitalWrite(GpsVccPin, LOW)//PNP
#define GpsOFF        digitalWrite(GpsVccPin, HIGH)
#define RfON          digitalWrite(RfPDPin, HIGH)
#define RfOFF         digitalWrite(RfPDPin, LOW)
#define RfPwrHigh     pinMode(RfPwrHLPin, INPUT)
#define RfPwrLow      pinMode(RfPwrHLPin, OUTPUT);digitalWrite(RfPwrHLPin, LOW)
#define RfPttON       digitalWrite(RfPttPin, HIGH)//NPN
#define RfPttOFF      digitalWrite(RfPttPin, LOW)
#define AprsPinInput  pinMode(12,INPUT);pinMode(13,INPUT);pinMode(14,INPUT);pinMode(15,INPUT)
#define AprsPinOutput pinMode(12,OUTPUT);pinMode(13,OUTPUT);pinMode(14,OUTPUT);pinMode(15,OUTPUT)

#define DEVMODE // Development mode. Uncomment to enable for debugging.

//****************************************************************************
// current callsign (josh t)
char  CallSign[7]="KQ4KNV"; //DO NOT FORGET TO CHANGE YOUR CALLSIGN
// callNumber -1 for testing purposes
int   CallNumber=-1; //SSID http://www.aprs.org/aprs11/SSIDs.txt
char  Symbol='O'; // '/O' for balloon, '/>' for car, for more info : http://www.aprs.org/symbols/symbols-new.txt
bool alternateSymbolTable = false ; //false = '/' , true = '\'

char Frequency[9]="144.3900"; //default frequency. 144.3900 for US, 144.8000 for Europe

//char comment[50] = "http://www.lightaprs.com"; // Max 50 char
char comment[50] = "TEST kscucf.org TEST"; // Max 50 char
char StatusMessage[50] = "LightAPRS by TA9OHC & TA2MUN"; 
//*****************************************************************************

// time interval for TXs
unsigned int   BeaconWait=10; //TESTING APRS
//unsigned int   BeaconWait=60;  //seconds sleep for next beacon (TX).
unsigned int   BattWait=60;    //seconds sleep if super capacitors/batteries are below BattMin (important if power source is solar panel) 
float BattMin=4.5;        // min Volts to wake up.
float DraHighVolt=8.0;    // min Volts for radio module (DRA818V) to transmit (TX) 1 Watt, below this transmit 0.5 Watt. You don't need 1 watt on a balloon. Do not change this.
//float GpsMinVolt=4.0; //min Volts for GPS to wake up. (important if power source is solar panel) 

boolean aliveStatus = true; //for tx status message on first wake-up just once.

//do not change WIDE path settings below if you don't know what you are doing :) 
byte  Wide1=1; // 1 for WIDE1-1 path
byte  Wide2=1; // 1 for WIDE2-1 path

/**
Airborne stations above a few thousand feet should ideally use NO path at all, or at the maximum just WIDE2-1 alone.  
Due to their extended transmit range due to elevation, multiple digipeater hops are not required by airborne stations.  
Multi-hop paths just add needless congestion on the shared APRS channel in areas hundreds of miles away from the aircraft's own location.  
NEVER use WIDE1-1 in an airborne path, since this can potentially trigger hundreds of home stations simultaneously over a radius of 150-200 miles. 
 */
int pathSize=2; // 2 for WIDE1-N,WIDE2-N ; 1 for WIDE2-N
boolean autoPathSizeHighAlt = true; //force path to WIDE2-N only for high altitude (airborne) beaconing (over 1.000 meters (3.280 feet)) 

//boolean GpsFirstFix=false;
boolean ublox_high_alt_mode = false;

static char telemetry_buff[100];// telemetry buffer
uint16_t TxCount = 1;

TinyGPSPlus gps;
Adafruit_BMP085 bmp;
String serialCommand;


void setup() {
  wdt_enable(WDTO_8S);
  analogReference(INTERNAL2V56);
  pinMode(RfPDPin, OUTPUT);
  pinMode(GpsVccPin, OUTPUT);
  pinMode(RfPwrHLPin, OUTPUT);
  pinMode(RfPttPin, OUTPUT);
  pinMode(BattPin, INPUT);
  pinMode(PIN_DRA_TX,INPUT);

  RfOFF;
  GpsOFF;
  RfPwrLow;
  RfPttOFF;
  AprsPinInput;

  Serial.begin(57600);
  Serial1.begin(9600);
#if defined(DEVMODE)
  Serial.println(F("Start"));
#endif
      
  APRS_init(ADC_REFERENCE, OPEN_SQUELCH);
  APRS_setCallsign(CallSign,CallNumber);
  APRS_setDestination("APLIGA", 0);
  APRS_setMessageDestination("APLIGA", 0);
  APRS_setPath1("WIDE1", Wide1);
  APRS_setPath2("WIDE2", Wide2);
  APRS_useAlternateSymbolTable(alternateSymbolTable); 
  APRS_setSymbol(Symbol);
  //increase following value (for example to 500UL) if you experience packet loss/decode issues. 
  APRS_setPreamble(350UL);  
  APRS_setPathSize(pathSize);

  configDra818(Frequency);

  bmp.begin();
 
}

void loop() {
   wdt_reset();
  
  if (readBatt() > BattMin) {
  
  if(aliveStatus){

      //send status tx on startup once (before gps fix)
      
      #if defined(DEVMODE)
        Serial.println(F("Sending"));
      #endif
      sendStatus();
      #if defined(DEVMODE)
        Serial.println(F("Sent"));
      #endif
      
      aliveStatus = false;
      
   }
    
    updateGpsData(1000);
    gpsDebug();

    
    if ((gps.location.age() < 1000 || gps.location.isUpdated()) && gps.location.isValid()) {
      if (gps.satellites.isValid() && (gps.satellites.value() > 3)) {
      updatePosition();
      updateTelemetry();
      
      //GpsOFF;
      setGPS_PowerSaveMode();
      //GpsFirstFix=true;

      if(autoPathSizeHighAlt && gps.altitude.feet()>3000){
            //force to use high altitude settings (WIDE2-n)
            APRS_setPathSize(1);
        } else {
            //use defualt settings  
            APRS_setPathSize(pathSize);
        }
      
      //send status message every 60 minutes
      if(gps.time.minute() == 30){               
        sendStatus();       
      } else {

         sendLocation();

      }

      freeMem();
      Serial.flush();
      sleepSeconds(BeaconWait);

      } else {
#if defined(DEVMODE)
      Serial.println(F("Not enough sattelites"));
#endif
      }
    } 
  } else {

    sleepSeconds(BattWait);
    
  }
  
}

void aprs_msg_callback(struct AX25Msg *msg) {
  //do not remove this function, necessary for LibAPRS
}

void sleepSeconds(int sec) {  
  //if(GpsFirstFix)GpsOFF;//sleep gps after first fix
  RfOFF;
  RfPttOFF;
  Serial.flush();
  wdt_disable();
  for (int i = 0; i < sec; i++) {
    //if(readBatt() < GpsMinVolt) GpsOFF;  //(for pico balloon only)
    LowPower.powerDown(SLEEP_1S, ADC_OFF, BOD_ON);   
  }
   wdt_enable(WDTO_8S);
}
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

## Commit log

2023-03-04 added ground folder
2023-10-13 log sensor data to SD
2023-10-16 arduino console plot
2024-03-20 primary board
    [PrimaryBoard.brd, PrimaryBoard.sch]
2024-03-26 comms board
    [CommunicationBoard.brd, CommunicationBoard.sch]
2024-03-26 primary board updates
    [PrimaryBoard.brd, PrimaryBoard.sch]
2024-03-26 move antenna mounting holes
    [CommunicationBoard.brd]
2024-03-26 round board corners
    [CommunicationBoard.brd, PrimaryBoard.brd]
2024-03-26 remove thermal isolation
    [CommunicationBoard.brd]
2024-03-26 dont push gerber zips
2024-03-26 shrink primary to 90mm
    [PrimaryBoard.brd, PrimaryBoard.sch]
2024-03-26 update comms silkscreen
    [CommunicationBoard.brd]
2024-03-27 primary board redesign
    [PrimaryBoard.brd, PrimaryBoard.sch]
2024-03-27 franks files
    [power_board.brd, sensor_board.brd, sensor_board.sch]
2024-03-29 final touches
    [CommunicationBoard.brd, CommunicationBoard.sch, PrimaryBoard.brd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]
2024-03-31 final board tweaks
    [CommunicationBoard.brd, CommunicationBoard.sch, PrimaryBoard.brd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]
2024-03-31 rename boards
    [PowerBoard.brd, PowerBoard.sch, SensorBoard.brd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]
2024-03-31 rev1 changes
    [PowerBoard.brd, PowerBoard.sch, PrimaryBoard.brd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]
2024-03-31 update caps on pb
    [PowerBoard.brd, PowerBoard.sch]
2024-10-19 update pin numbers
2024-10-22 get adc measurements
2024-11-18 camera code
2025-02-06 update TODO
    [PrimaryBoard.sch]
2025-02-13 removed servo related code
    murder
2025-05-28 Thermistor Implementation
2025-07-07 Removed Averaging of Temperatures
2025-07-07 Fixed ADC code

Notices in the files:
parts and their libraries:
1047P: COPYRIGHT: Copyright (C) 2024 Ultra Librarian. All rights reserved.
